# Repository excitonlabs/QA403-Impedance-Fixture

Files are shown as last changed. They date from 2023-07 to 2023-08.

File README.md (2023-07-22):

# QA403 Impedance Fixture

A test fixture for the QuantAsylum QA403 for measuring impedance based on Matt's blog posts:
* https://quantasylum.com/blogs/news/speaker-impedance-measurements
* https://quantasylum.com/blogs/news/measuring-input-impedance

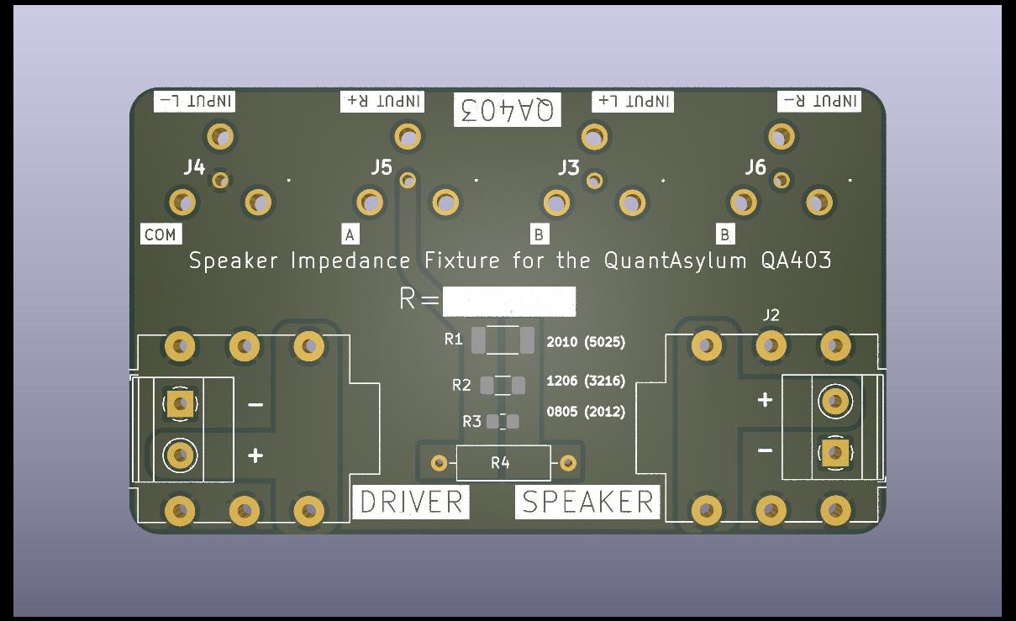
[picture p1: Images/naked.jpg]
PCB only


The PCB is fairly flexible, there are three footprints for SMD currents sense resistors and a single through-hole footprint. These are in parallel so the expectation is you place one and write the value on the silk screen space provided. The PCB also had an additional BNC for the L- input which may be useful in push-pull differential measurements.

## Questions

Forum post https://forum.quantasylum.com/t/comments-welcomed-on-test-fixture-pcb-for-impedance-measurements

## How to get this PCB

0. Wait until I confirm everything works (PCBs will arrive this week).
1. Order PCBs from a fab. house such as https://jlcpcb.com or email me I have may spare ones.
2. Order components from the BOM

## BOM

See datasheets in `/Parts` directory.

* Optional 2 x [MKDSN 1,5/ 2-5,08 1729128, terminal block](https://www.phoenixcontact.com/en-us/products/printed-circuit-board-terminal-mkdsn-15-2-508-1729128)
* Optional 2 x [Neutrik NMJ6HCD2, Jack socket](https://www.neutrik.com/en/product/nmj6hcd2)
* 4  x [TE Connectivity 5221123-2, BNC socket](https://www.te.com/usa-en/product-5221123-2.html)
* 1 x current sense resistor of the following types:
  * 2012 (5025)
  * 1206 (3216)
  * 0805 (2012)
  * Through-hole 

## Examples

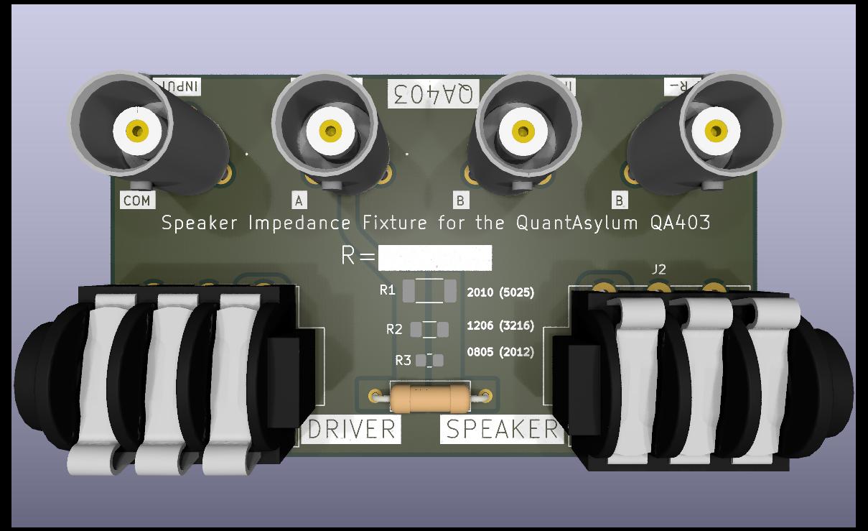
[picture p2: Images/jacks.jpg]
PCB with jack sockets

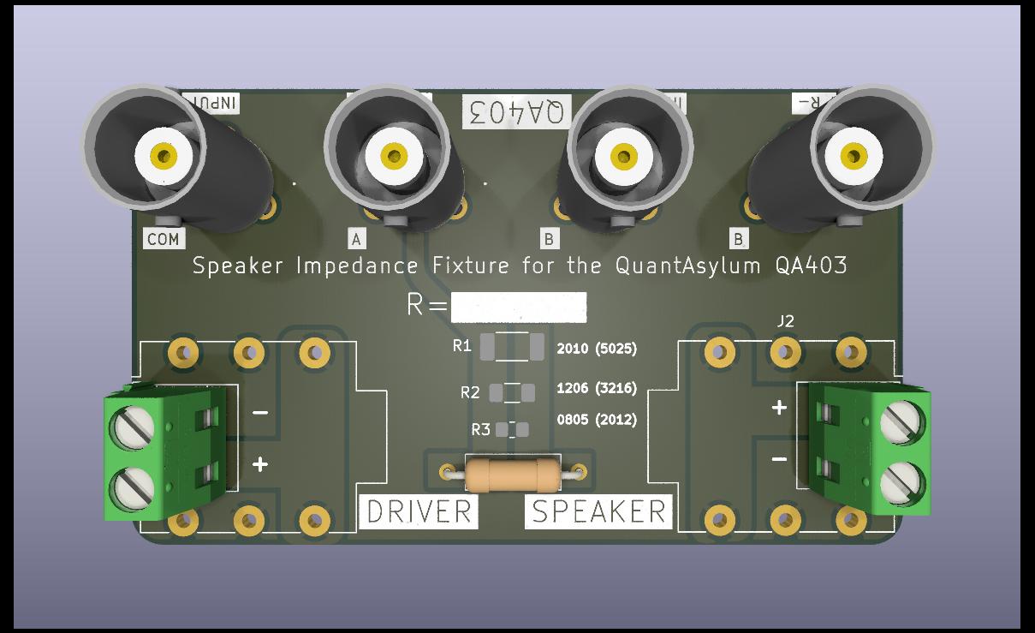
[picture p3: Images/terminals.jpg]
PCB with terminals

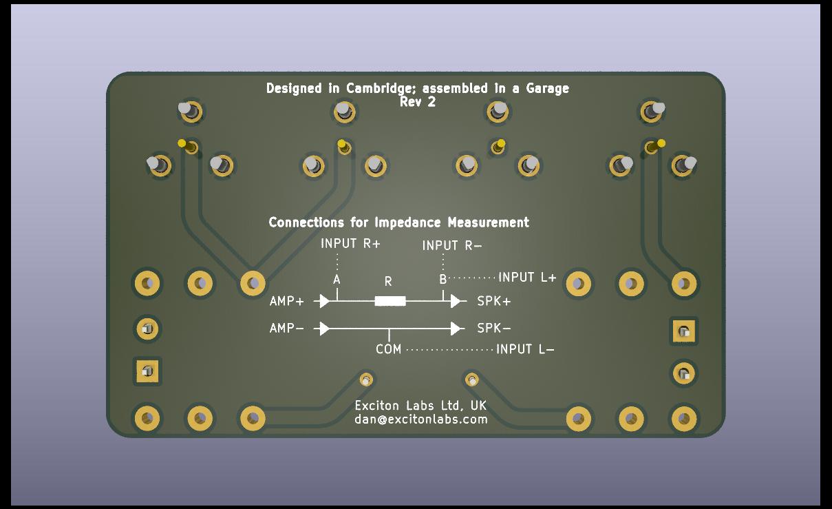
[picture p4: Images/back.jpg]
PCB's back


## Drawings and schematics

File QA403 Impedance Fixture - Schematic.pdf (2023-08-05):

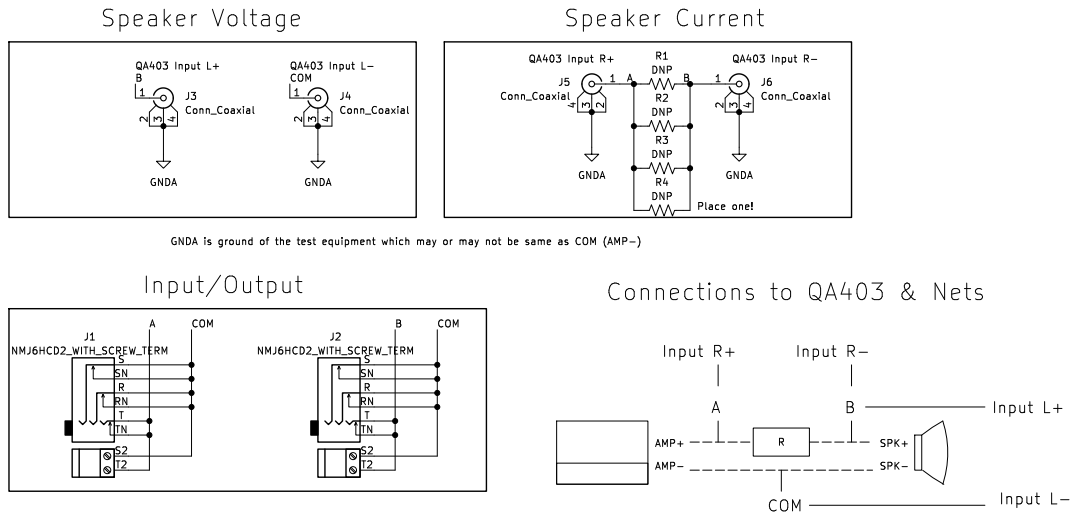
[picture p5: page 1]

Id: 1/1 Title: Speaker Impedance Fixture

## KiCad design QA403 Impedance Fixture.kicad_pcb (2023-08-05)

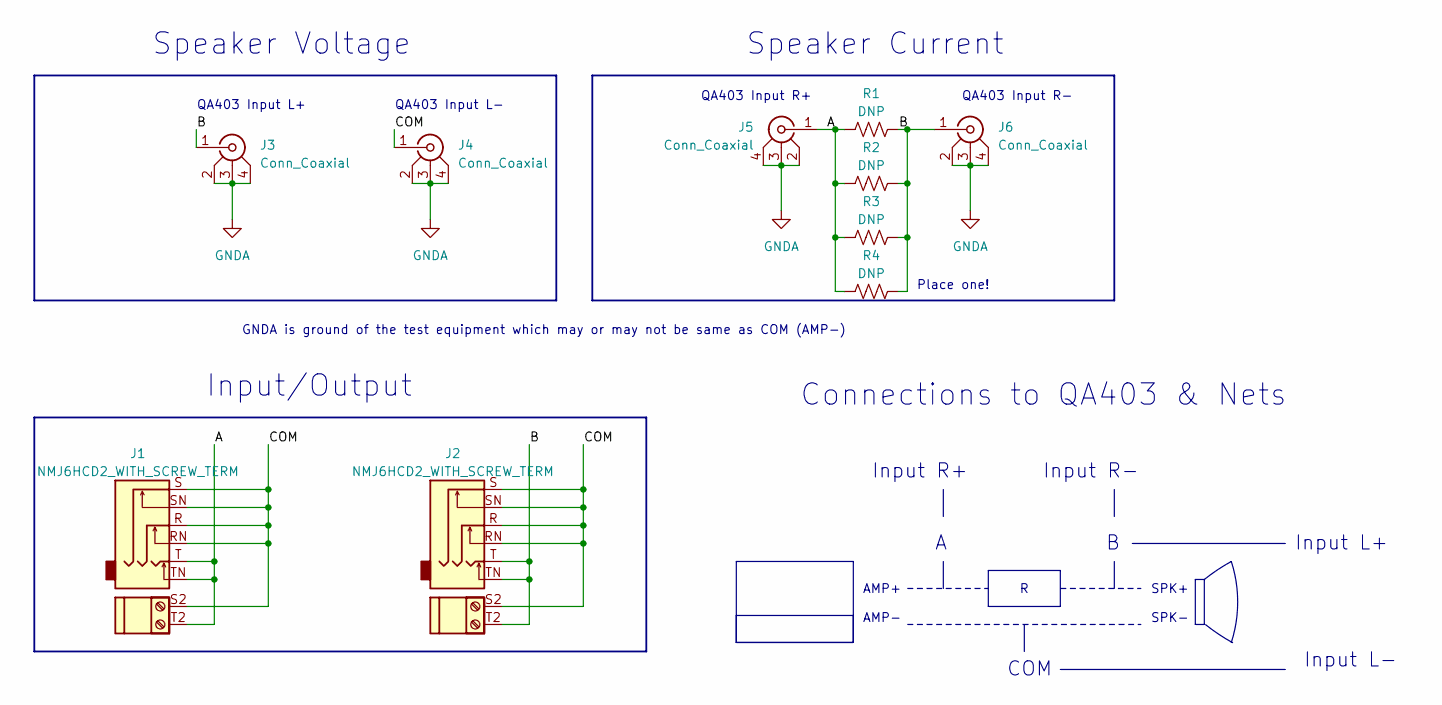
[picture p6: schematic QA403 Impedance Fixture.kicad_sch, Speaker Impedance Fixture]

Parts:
J1, J2: NMJ6HCD2_WITH_SCREW_TERM; Dual_Jack_6.35mm_Neutrik_NMJ6HCD2_Horizontal_TerminalBlock_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
J3, J4, J5, J6: Conn_Coaxial; 52211232
R1: DNP; R_2010_5025Metric_Pad1.40x2.65mm_HandSolder
R2: DNP; R_1206_3216Metric_Pad1.30x1.75mm_HandSolder
R3: DNP; R_0805_2012Metric_Pad1.20x1.40mm_HandSolder
R4: DNP; R_Axial_DIN0309_L9.0mm_D3.2mm_P12.70mm_Horizontal

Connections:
/A: J1.T, J1.T2, J1.TN, J5.1 (In), R1.1, R2.1, R3.1, R4.1
/B: J2.T, J2.T2, J2.TN, J3.1 (In), J6.1 (In), R1.2, R2.2, R3.2, R4.2
/COM: J1.R, J1.RN, J1.S, J1.S2, J1.SN, J2.R, J2.RN, J2.S, J2.S2, J2.SN, J4.1 (In)
GNDA: J3.2 (Ext), J3.3 (Ext), J3.4 (Ext), J4.2 (Ext), J4.3 (Ext), J4.4 (Ext), J5.2 (Ext), J5.3 (Ext), J5.4 (Ext), J6.2 (Ext), J6.3 (Ext), J6.4 (Ext)

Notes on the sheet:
Speaker Current
Speaker Voltage
QA403 Input R+
QA403 Input L+
Input L+
GNDA is ground of the test equipment which may or may not be same as COM (AMP-)
Input L-
Input/Output
AMP+ AMP-
Input R-
SPK+ SPK-
Input R+
QA403 Input R-
QA403 Input L-
Connections to QA403 & Nets
COM
Place one!

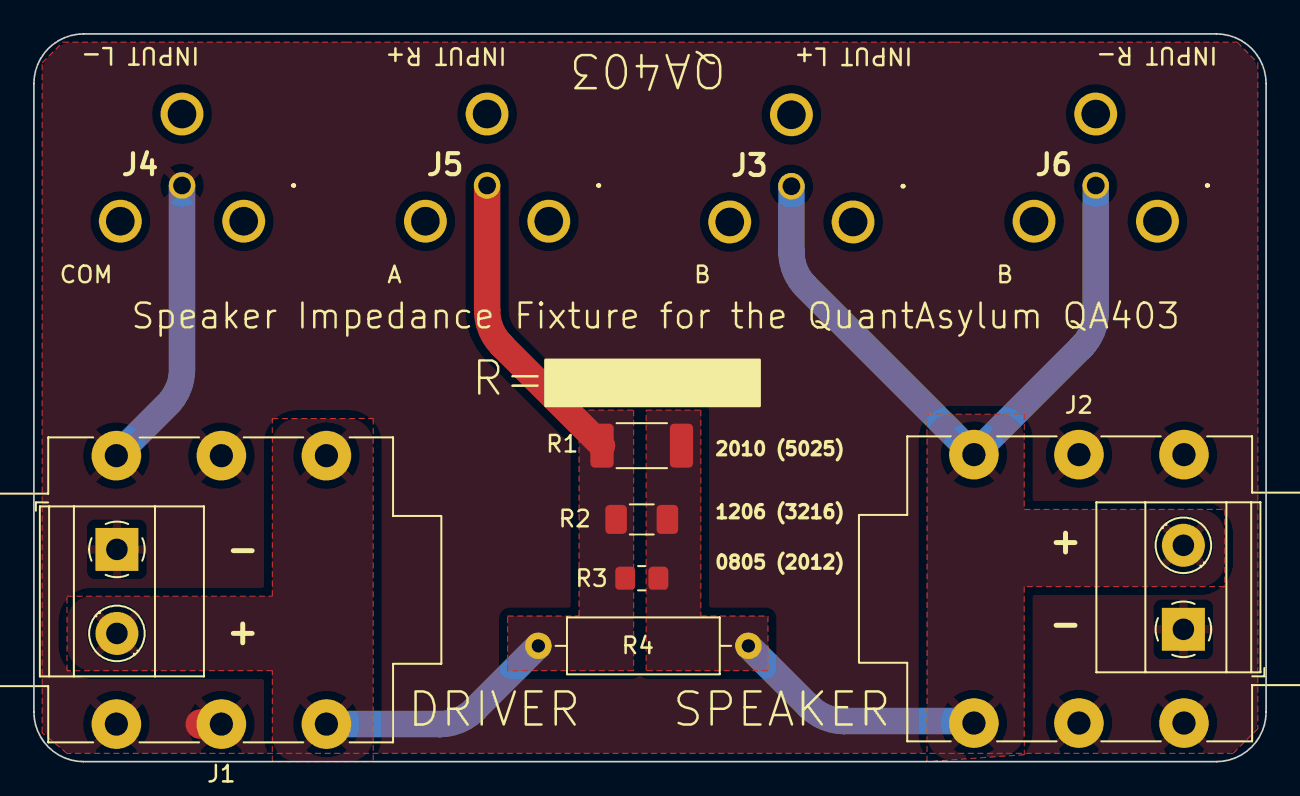
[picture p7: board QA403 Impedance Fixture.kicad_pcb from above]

Board: 2 copper layers, 74.5 x 44.0 mm, 10 parts (0 on the bottom side), 4 nets.
